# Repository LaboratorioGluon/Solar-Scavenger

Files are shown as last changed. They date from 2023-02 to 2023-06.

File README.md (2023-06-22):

# Solar Scavenger

Os presento el barco **Solar Scavenger** participante de la VI Regata Solar en Baiona!

El resultado: Primer premio en diseño y tercero en regata!

Todo está desarrollado en directo, desde la PCB, diseño 3D, software y montaje! (Link abajo)

## Materiales usados:

| Nombre | Descripción |
|---|---|
| [A2212 1000 KV](https://s.click.aliexpress.com/e/_DB0ZUoN) | Motor brushless outrunner para el barco|
| [ESC 4S 40A](https://s.click.aliexpress.com/e/_DB3iqU5) | Controlador de velocidad ESC |
| [ESP32](https://s.click.aliexpress.com/e/_DdJJJ5L) | Cerebro del controlador |

## PCB

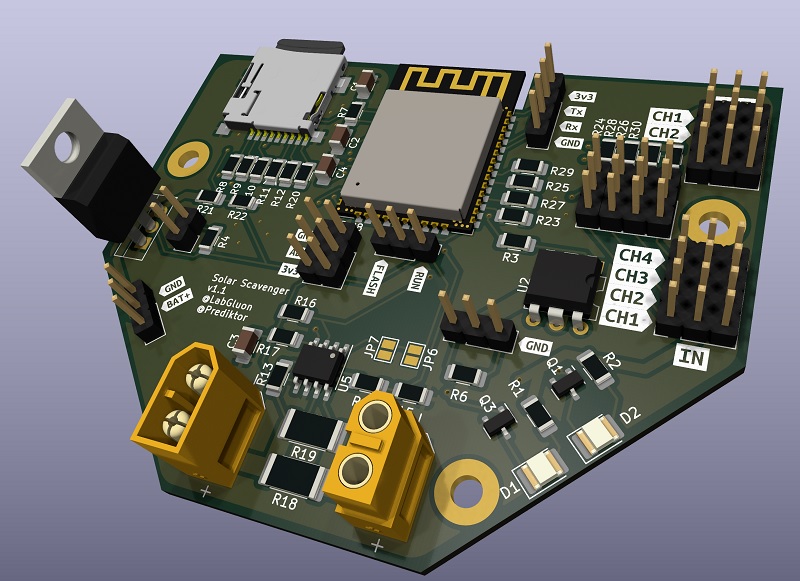
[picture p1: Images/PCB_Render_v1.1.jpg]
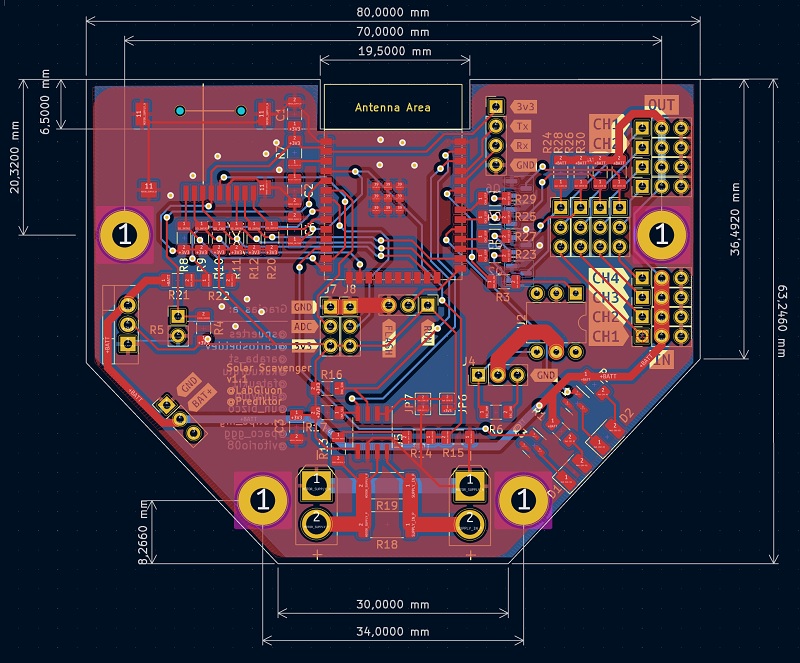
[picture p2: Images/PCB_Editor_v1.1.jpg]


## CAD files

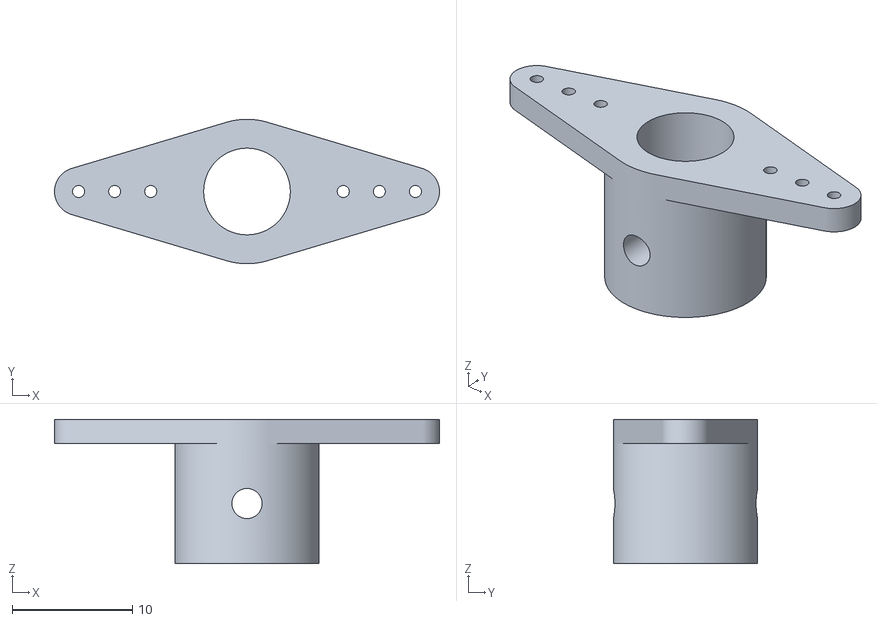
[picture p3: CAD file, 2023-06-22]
3D/stls/Caja_Control/SoporteEje - Part 1.stl
32.0 x 12.0 x 12.0

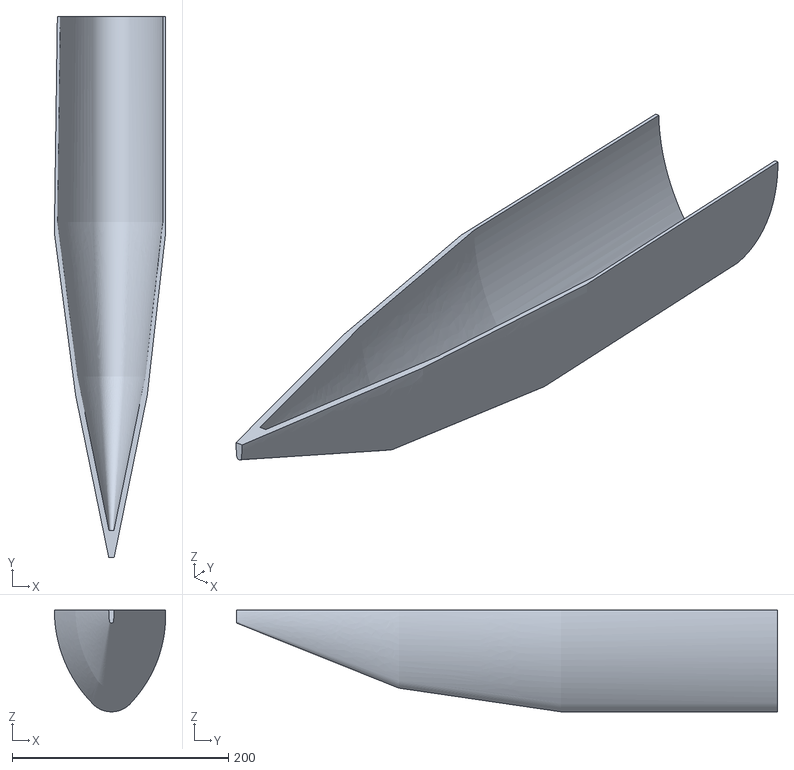
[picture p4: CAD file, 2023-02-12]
3D/stls/Casco_barco-Cut.stl
102.9 x 500.0 x 94.0

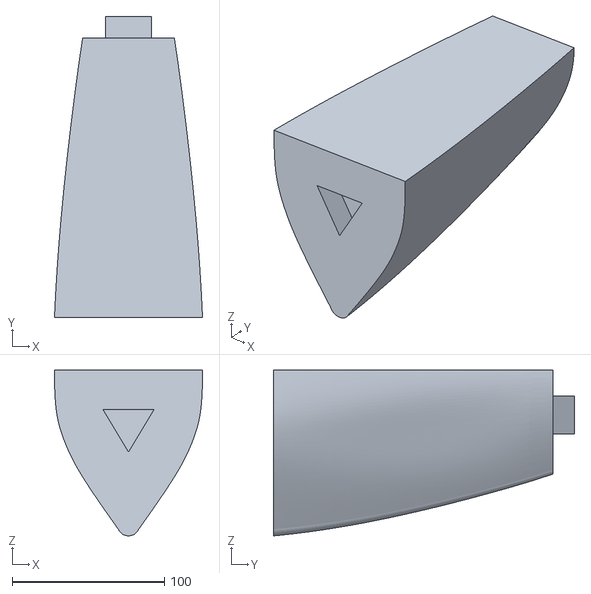
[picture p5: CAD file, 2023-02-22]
3D/stls/Casco_barco/Casco2.stl
97.4 x 198.0 x 109.1

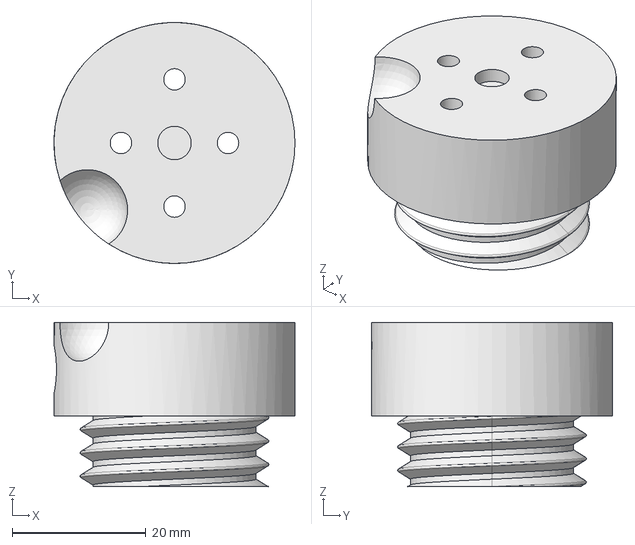
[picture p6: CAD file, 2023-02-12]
3D/Direccion_sg90.FCStd
36.0 x 36.0 x 24.5 mm

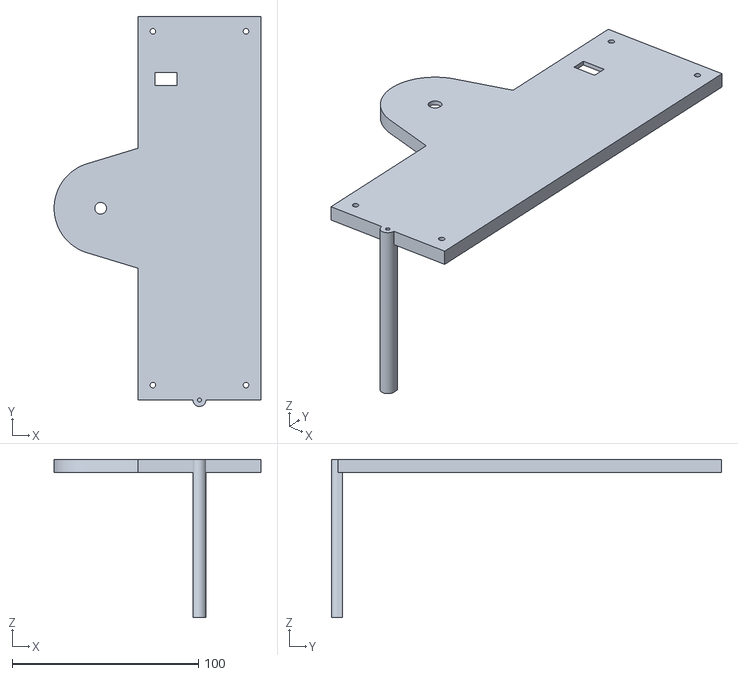
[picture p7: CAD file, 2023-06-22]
3D/stls/Caja_Control/CajaControl_Tapa.stl
111.1 x 209.5 x 85.0

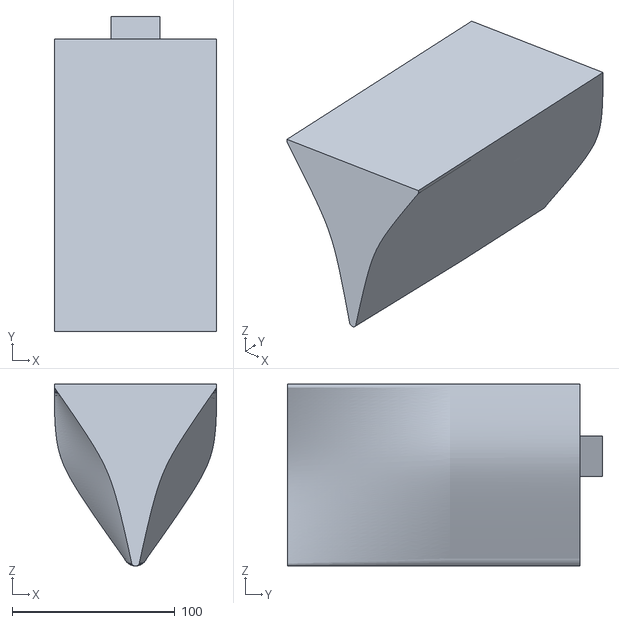
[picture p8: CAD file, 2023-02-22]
3D/stls/Casco_barco/Casco6_cola.stl
100.0 x 194.0 x 112.0

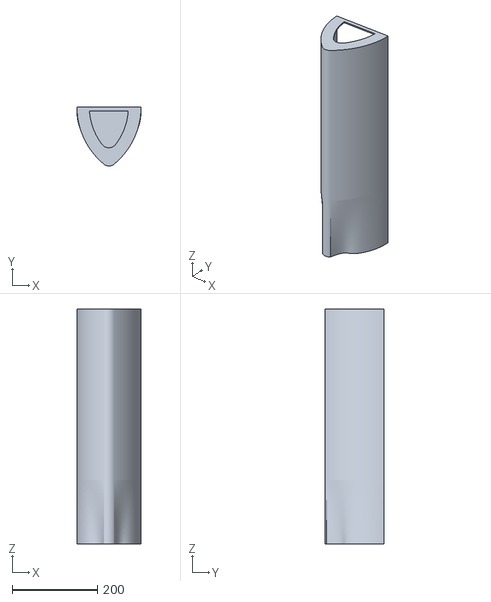
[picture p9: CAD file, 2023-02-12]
3D/stls/Hull_trasera.stl
150.5 x 138.3 x 550.0

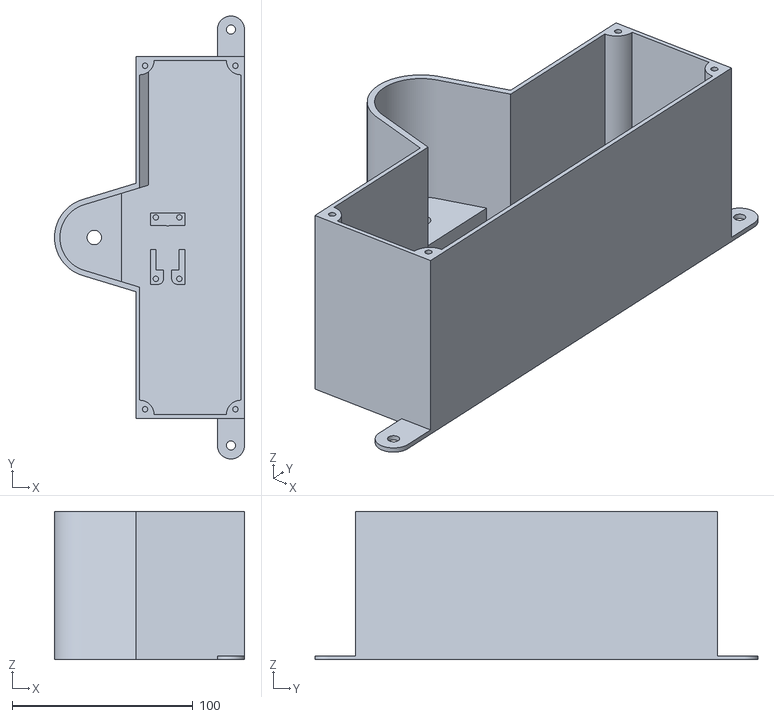
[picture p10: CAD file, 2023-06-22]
3D/stls/Caja_Control/CajaControl_principal.stl
105.1 x 245.0 x 82.0

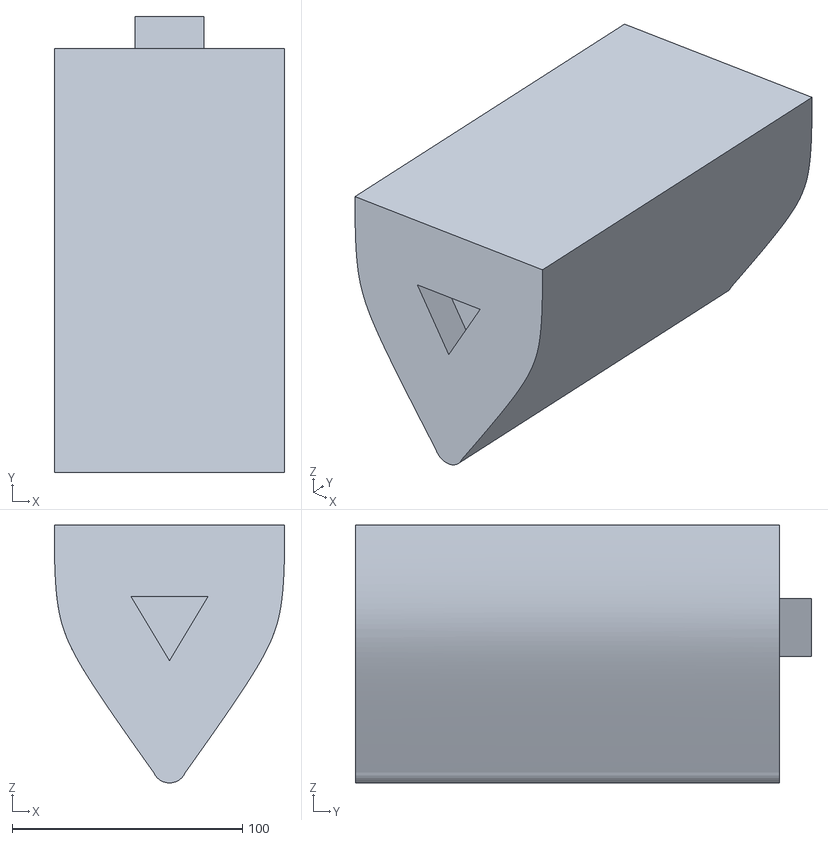
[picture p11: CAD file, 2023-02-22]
3D/stls/Casco_barco/Casco4.stl
100.0 x 198.0 x 112.0

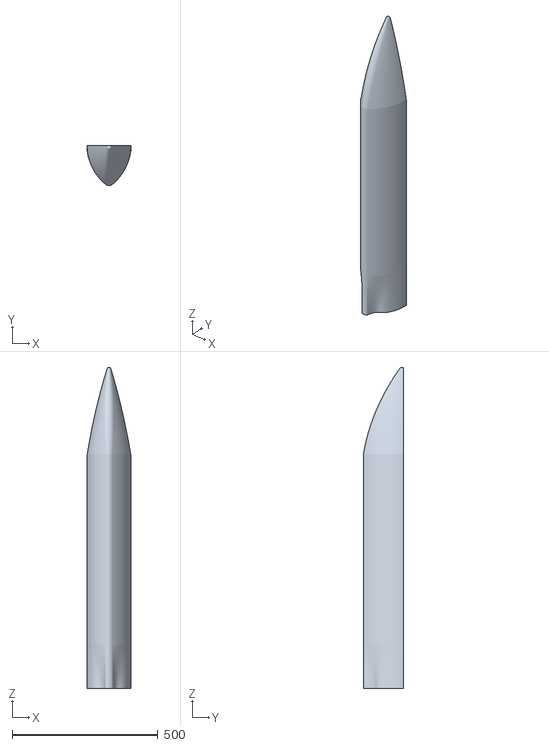
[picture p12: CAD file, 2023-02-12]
3D/stls/Hull_v01.stl
150.5 x 138.2 x 1100.0

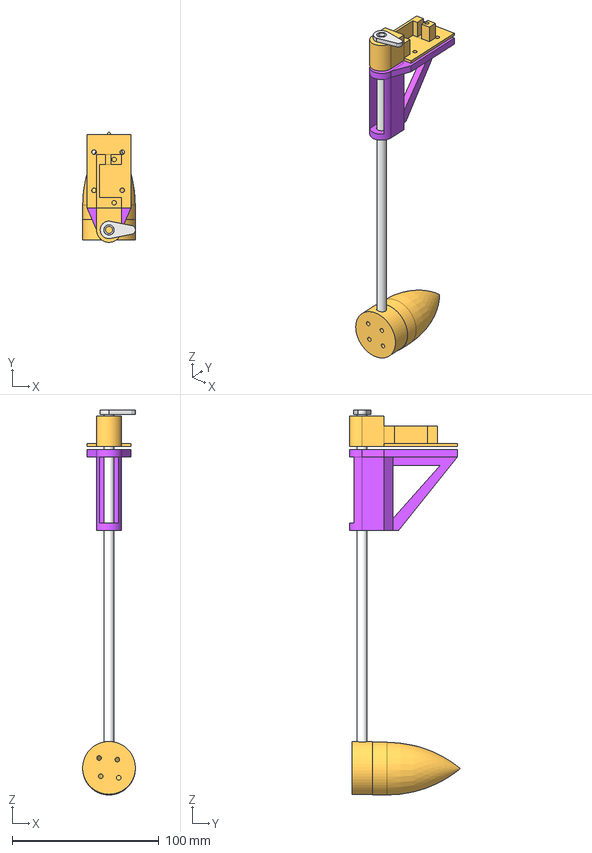
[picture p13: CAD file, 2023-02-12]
3D/Direccion_sg90_v2.FCStd
36.0 x 75.5 x 262.5 mm
SoporteSevo
EjeDireccion
EjeSaliente
AletaSoporte

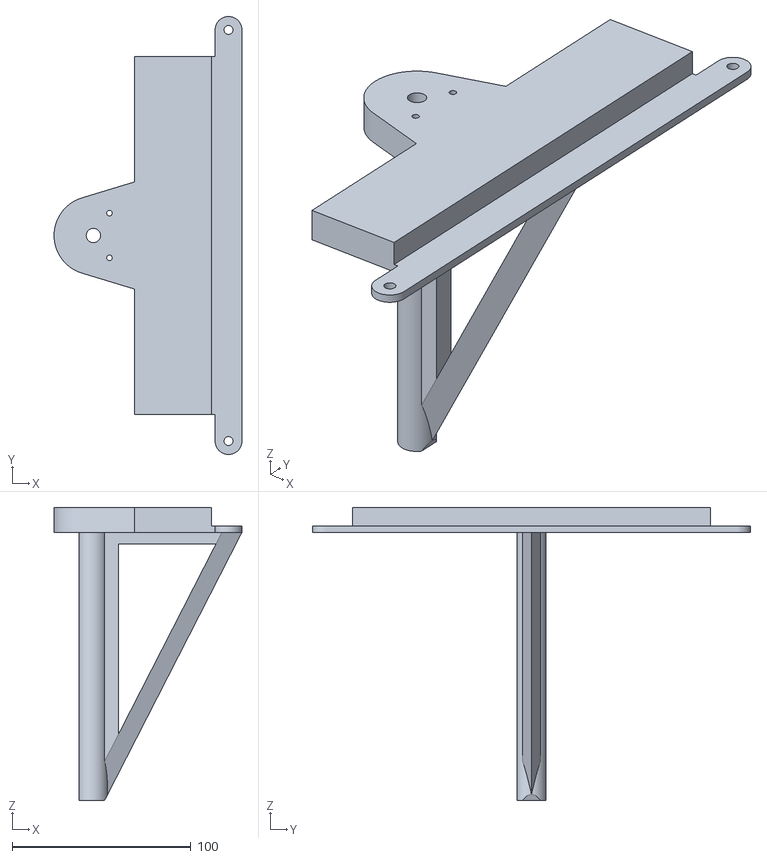
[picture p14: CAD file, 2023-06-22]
3D/stls/Caja_Control/CajaControl_Eje.stl
105.1 x 245.0 x 164.0

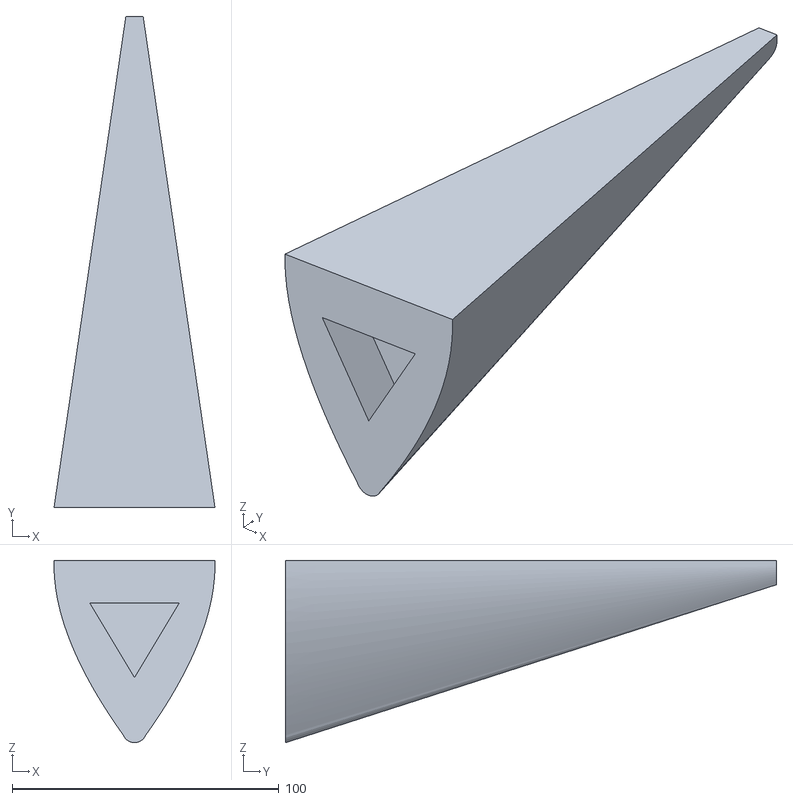
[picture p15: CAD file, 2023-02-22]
3D/stls/Casco_barco/Casco1_punta.stl
60.3 x 184.0 x 68.4

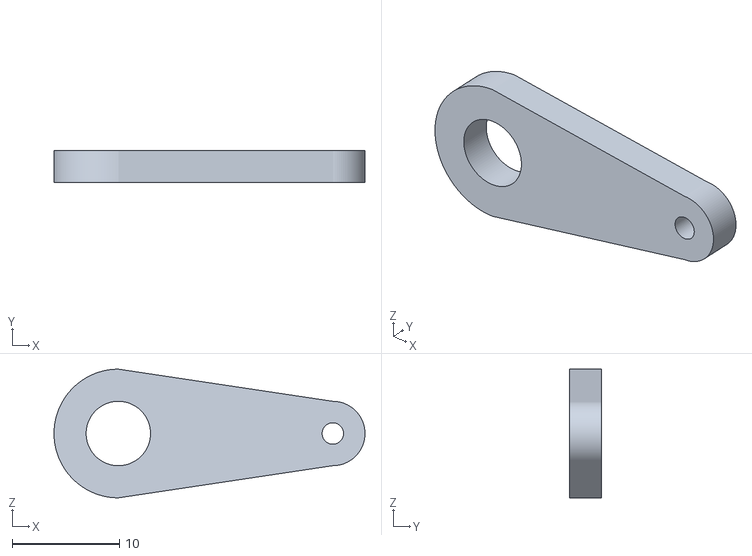
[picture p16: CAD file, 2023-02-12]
3D/stls/Test_Soporte_Brazo.stl
29.0 x 3.00 x 12.0

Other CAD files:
3D/Casco_barco.FCStd
3D/Casco_barco_v0.FCStd
3D/stls/Casco_barco/Casco5.stl
3D/stls/Direccion_sg90-AletaSoporte.stl
3D/Casco v14.f3d
3D/Direccion_sg90_v1.FCStd
3D/stls/Casco_barco/Casco3.stl
3D/stls/Direccion_sg90-AletaSoporte_v2.stl
3D/stls/Direccion_sg90-Body.stl
3D/stls/Direccion_sg90-Body_v2.stl
3D/stls/Hull_frontal.stl
3D/stls/Test_Soporte_Barra.stl
3D/stls/Test_Soporte_Servo.stl

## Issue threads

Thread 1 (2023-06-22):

Mejoras V2.0

LaboratorioGluon, 2023-06-22:
Elemento identificación (Algo llamativo)
Menos peso (y corchopan?)
Pitorrillo de motor
Hélice más pequeña y que gire más rápido
Dirección por timón
--> Trimarán?? (Ha ganado en la encuenta de expertos)
Más estrechos, porqué? (En piragüas se nota, más afilado -> más rapido)
Hidrojet (Si lo encontramos)

== Electronica/Sw ==
LEds de colores ?
Interruptor on/off
Condensadores
// Poner RTC en la electrónica? Poder diferenciar carreras/tiempos/eventos
Añadir GPS/IMU
Añadir todos los datos a la SD
EEPROM para guardar datos?

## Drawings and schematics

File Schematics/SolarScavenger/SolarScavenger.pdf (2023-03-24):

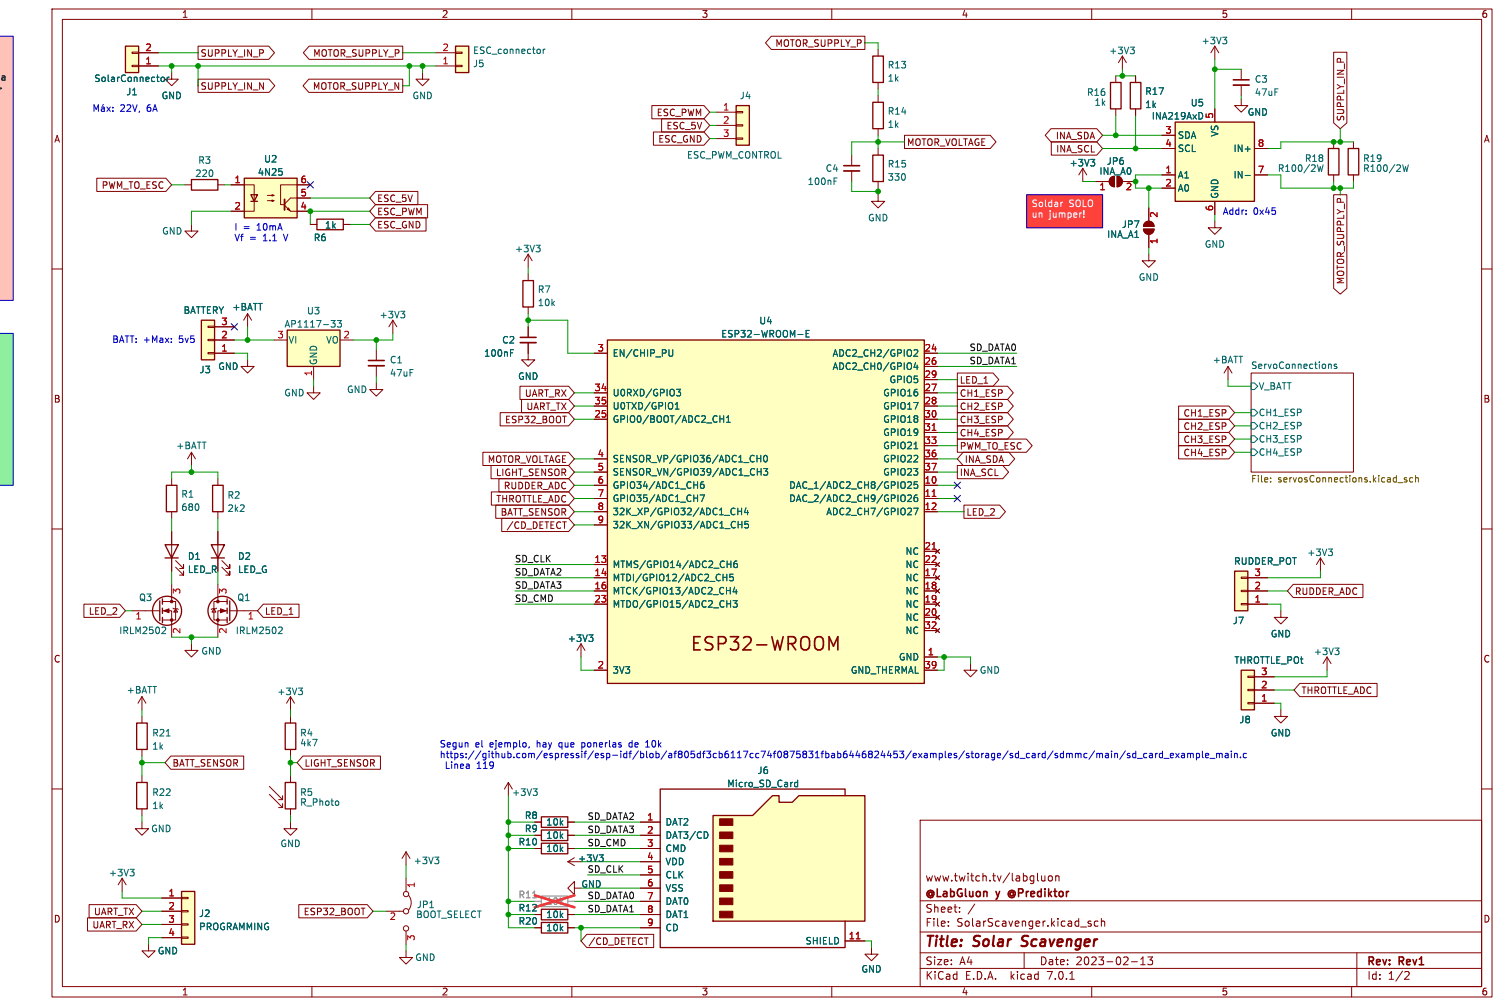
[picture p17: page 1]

þÿMáx: 22V, 6A Release Notes v1.1 TODOS:
[X] Fix: Enable chip + þÿAñadir RC al pin 3

Segun el ejemplo, hay que ponerlas de 10k https://github.com/espressif/esp-idf/blob/af805df3cb6117cc74f0875831fbab6446824453/examples/storage/sd_card/sdmmc/main/sd_card_example_main.c Linea 119 BATT: +Max: 5v5

www.twitch.tv/labgluon
Id: 1/2 Title: Solar Scavenger File: SolarScavenger.kicad_sch Sheet: / @LabGluon y @Prediktor

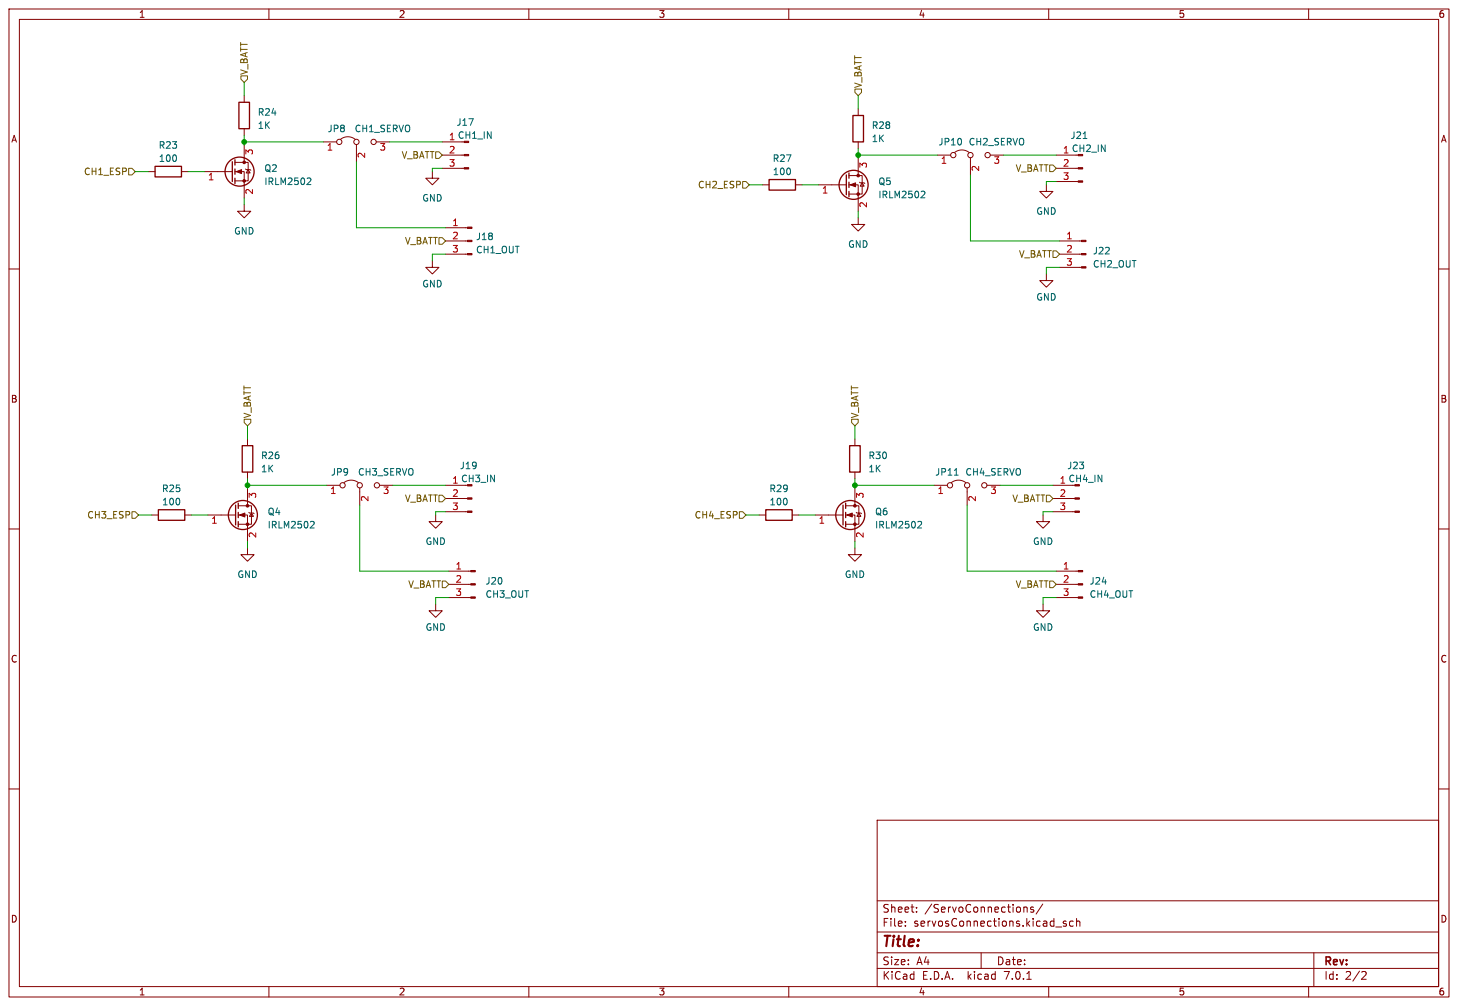
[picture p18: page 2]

Id: 2/2 Title: File: servosConnections.kicad_sch Sheet: /ServoConnections/

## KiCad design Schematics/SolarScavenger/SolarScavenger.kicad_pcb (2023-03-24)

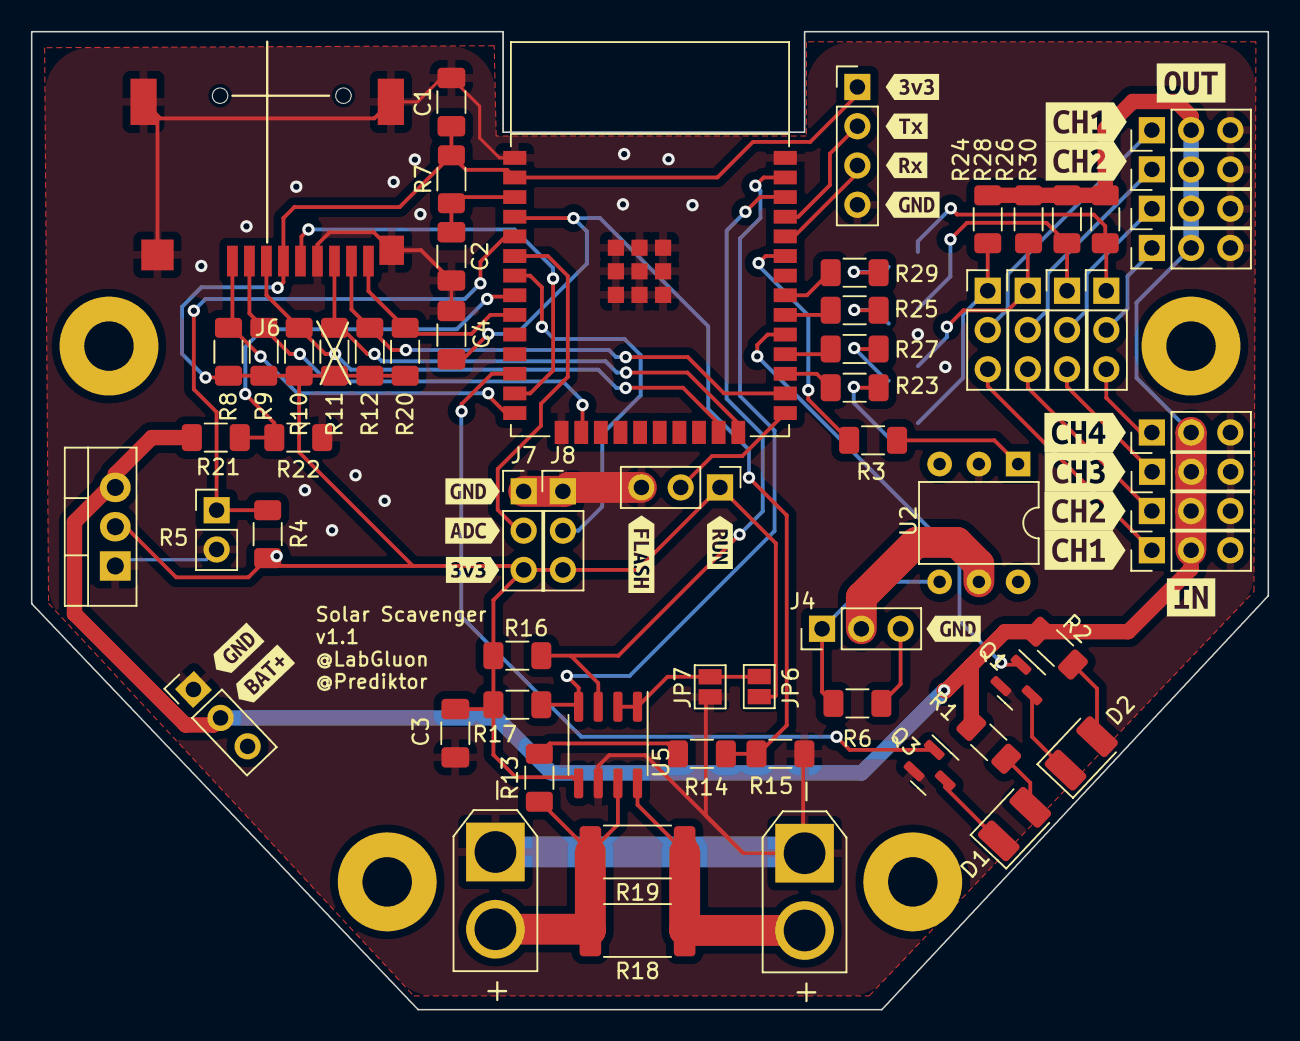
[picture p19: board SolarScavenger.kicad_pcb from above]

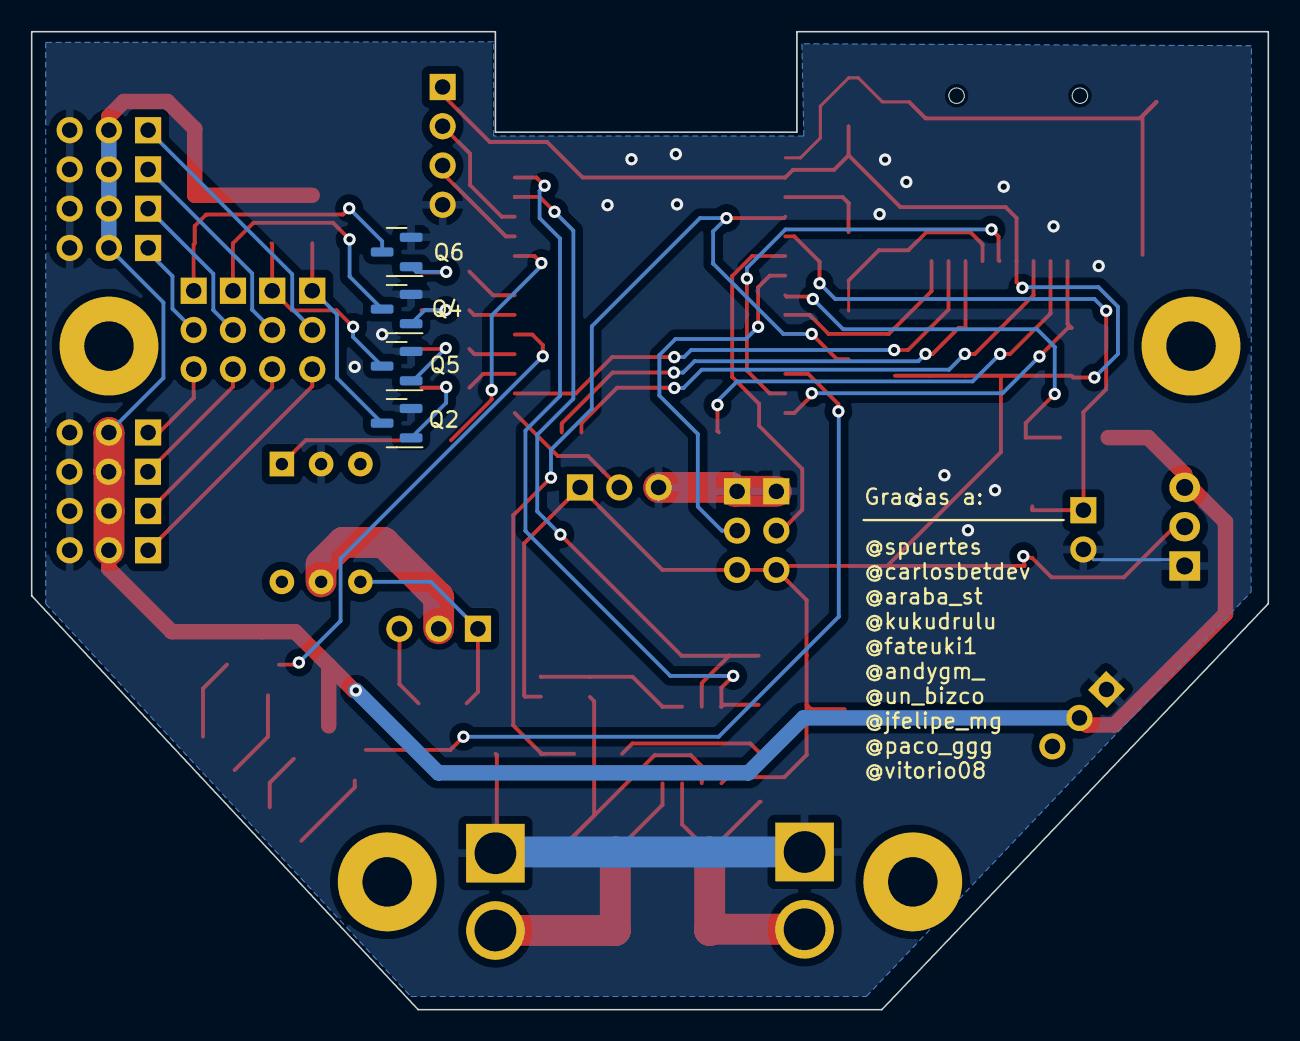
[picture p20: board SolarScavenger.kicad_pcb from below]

Board: 2 copper layers, 80.0 x 63.3 mm, 89 parts (4 on the bottom side), 56 nets.

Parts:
C1, C3: 47uF; C_1206_3216Metric_Pad1.33x1.80mm_HandSolder
C2, C4: 100nF; C_1206_3216Metric_Pad1.33x1.80mm_HandSolder
D1: LED_R; LED_1210_3225Metric_Pad1.42x2.65mm_HandSolder
D2: LED_G; LED_1210_3225Metric_Pad1.42x2.65mm_HandSolder
J1: SolarConnector; AMASS_XT30U-M_1x02_P5.0mm_Vertical
J2: PROGRAMMING; PinHeader_1x04_P2.54mm_Vertical
J3: BATTERY; PinHeader_1x03_P2.54mm_Vertical
J4: ESC_PWM_CONTROL; PinHeader_1x03_P2.54mm_Vertical
J5: ESC_connector; AMASS_XT30U-M_1x02_P5.0mm_Vertical
J6: Micro_SD_Card; microSD-Receptacle-SelfEject
J7: RUDDER_POT; PinHeader_1x03_P2.54mm_Vertical
J8: THROTTLE_POt; PinHeader_1x03_P2.54mm_Vertical
J17: CH1_IN; PinHeader_1x03_P2.54mm_Vertical
J18: CH1_OUT; PinHeader_1x03_P2.54mm_Vertical
J19: CH3_IN; PinHeader_1x03_P2.54mm_Vertical
J20: CH3_OUT; PinHeader_1x03_P2.54mm_Vertical
J21: CH2_IN; PinHeader_1x03_P2.54mm_Vertical
J22: CH2_OUT; PinHeader_1x03_P2.54mm_Vertical
J23: CH4_IN; PinHeader_1x03_P2.54mm_Vertical
J24: CH4_OUT; PinHeader_1x03_P2.54mm_Vertical
JP1: BOOT_SELECT; PinHeader_1x03_P2.54mm_Vertical
JP6: INA_A0; SolderJumper-2_P1.3mm_Open_Pad1.0x1.5mm
JP7: INA_A1; SolderJumper-2_P1.3mm_Open_Pad1.0x1.5mm
JP8: CH1_SERVO; PinHeader_1x03_P2.54mm_Vertical
JP9: CH3_SERVO; PinHeader_1x03_P2.54mm_Vertical
JP10: CH2_SERVO; PinHeader_1x03_P2.54mm_Vertical
JP11: CH4_SERVO; PinHeader_1x03_P2.54mm_Vertical
Q1, Q2, Q3, Q4, Q5, Q6: IRLM2502; SOT-23
R1: 680; R_1206_3216Metric_Pad1.30x1.75mm_HandSolder
R2: 2k2; R_1206_3216Metric_Pad1.30x1.75mm_HandSolder
R3: 220; R_1206_3216Metric_Pad1.30x1.75mm_HandSolder
R4: 4k7; R_1206_3216Metric_Pad1.30x1.75mm_HandSolder
R5: R_Photo; PinHeader_1x02_P2.54mm_Vertical
R6, R13, R14, R16, R17, R21, R22: 1k; R_1206_3216Metric_Pad1.30x1.75mm_HandSolder
R7, R8, R9, R10, R11, R12, R20: 10k; R_1206_3216Metric_Pad1.30x1.75mm_HandSolder
R15: 330; R_1206_3216Metric_Pad1.30x1.75mm_HandSolder
R18, R19: R100/2W; R_2512_6332Metric_Pad1.40x3.35mm_HandSolder
R23, R25, R27, R29: 100; R_1206_3216Metric_Pad1.30x1.75mm_HandSolder
R24, R26, R28, R30: 1K; R_1206_3216Metric_Pad1.30x1.75mm_HandSolder
U2: 4N25; DIP-6_W7.62mm
U3: AP1117-33; TO-220-3_Vertical
U4: ESP32-WROOM-E; ESP32-WROOM-32E
U5: INA219AxD; SOIC-8_3.9x4.9mm_P1.27mm
kibuzzard-63EE93D3: G***; kibuzzard-63EE93D3
kibuzzard-63EE93FE, kibuzzard-63EE93FE#2: G***; kibuzzard-63EE93FE
kibuzzard-63EE940D: G***; kibuzzard-63EE940D
kibuzzard-63EE941D: G***; kibuzzard-63EE941D
kibuzzard-63EE9448: G***; kibuzzard-63EE9448
kibuzzard-63F11AB2: G***; kibuzzard-63F11AB2
kibuzzard-63F11AB7: G***; kibuzzard-63F11AB7
kibuzzard-63F11AC7: G***; kibuzzard-63F11AC7
kibuzzard-63F11AD1: G***; kibuzzard-63F11AD1
kibuzzard-63F11F4E: G***; kibuzzard-63F11F4E
kibuzzard-63F11F5A: G***; kibuzzard-63F11F5A
kibuzzard-63F118E7: G***; kibuzzard-63F118E7
kibuzzard-63F118F7: G***; kibuzzard-63F118F7
kibuzzard-63F127EF: G***; kibuzzard-63F127EF
kibuzzard-63F1280A: G***; kibuzzard-63F1280A
kibuzzard-63F12006: G***; kibuzzard-63F12006
kibuzzard-63F12026, kibuzzard-63F12026#2: G***; kibuzzard-63F12026
kibuzzard-63F12816: G***; kibuzzard-63F12816

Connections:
+3V3: C1.1, C3.1, J2.1, J6.4 (VDD), J7.3, J8.3, JP1.1 (A), JP6.1 (A), R4.1, R7.2, R8.2, R9.2, R10.2, R11.2, R12.2, R16.2, R17.2, R20.2, U3.2 (VO), U4.2 (3V3), U5.5 (VS)
+BATT: J3.2, J17.2, J18.2, J19.2, J20.2, J21.2, J22.2, J23.2, J24.2, R1.1, R2.1, R21.1, R24.2, R26.2, R28.2, R30.2, U3.3 (VI)
/SD_CLK: J6.5 (CLK), U4.13 (MTMS/GPIO14/ADC2_CH6)
/SD_CMD: J6.3 (CMD), R10.1, U4.23 (MTDO/GPIO15/ADC2_CH3)
/SD_DATA0: J6.7 (DAT0), R11.1, U4.24 (ADC2_CH2/GPIO2)
/SD_DATA1: J6.8 (DAT1), R12.1, U4.26 (ADC2_CH0/GPIO4)
/SD_DATA2: J6.1 (DAT2), R8.1, U4.14 (MTDI/GPIO12/ADC2_CH5)
/SD_DATA3: J6.2 (DAT3/CD), R9.1, U4.16 (MTCK/GPIO13/ADC2_CH4)
BATT_SENSOR: R21.2, R22.1, U4.8 (32K_XP/GPIO32/ADC1_CH4)
CH1_ESP: R23.1, U4.27 (GPIO16)
CH2_ESP: R27.1, U4.28 (GPIO17)
CH3_ESP: R25.1, U4.30 (GPIO18)
CH4_ESP: R29.1, U4.31 (GPIO19)
ESC_5V: J4.2, U2.5
ESC_GND: J4.3, R6.2
ESC_PWM: J4.1, R6.1, U2.4
ESP32_BOOT: JP1.2 (C), U4.25 (GPIO0/BOOT/ADC2_CH1)
INA_SCL: R17.1, U4.37 (GPIO23), U5.4 (SCL)
INA_SDA: R16.1, U4.36 (GPIO22), U5.3 (SDA)
LED_1: Q1.1 (G), U4.29 (GPIO5)
LED_2: Q3.1 (G), U4.12 (ADC2_CH7/GPIO27)
LIGHT_SENSOR: R4.2, R5.1, U4.5 (SENSOR_VN/GPIO39/ADC1_CH3)
MOTOR_SUPPLY_N: C1.2, C2.2, C3.2, C4.2, J1.1, J2.4, J3.1, J5.1, J6.6 (VSS), J6.11 (SHIELD), J7.1, J8.1, J17.3, J18.3, J19.3, J20.3, J21.3, J22.3, J23.3, J24.3, JP1.3 (B), JP7.1 (A), Q1.2 (S), Q2.2 (S), Q3.2 (S), Q4.2 (S), Q5.2 (S), Q6.2 (S), R5.2, R15.1, R22.2, U2.2, U3.1 (GND), U4.1 (GND), U4.15 (GND), U4.38 (GND), U4.39 (GND_THERMAL), U5.6 (GND)
MOTOR_SUPPLY_P: J5.2, R13.2, R18.2, R19.2, U5.7 (IN-)
MOTOR_VOLTAGE: C4.1, R14.1, R15.2, U4.4 (SENSOR_VP/GPIO36/ADC1_CH0)
unnamed: D1.2 (A), R1.2
unnamed: D1.1 (K), Q3.3 (D)
unnamed: D2.2 (A), R2.2
unnamed: D2.1 (K), Q1.3 (D)
unnamed: J17.1, JP8.3 (B)
unnamed: J18.1, JP8.2 (C)
unnamed: J19.1, JP9.3 (B)
unnamed: J20.1, JP9.2 (C)
unnamed: J21.1, JP10.3 (B)
unnamed: J22.1, JP10.2 (C)
unnamed: J23.1, JP11.3 (B)
unnamed: J24.1, JP11.2 (C)
unnamed: JP6.2 (B), JP7.2 (B), U5.1 (A1), U5.2 (A0)
unnamed: JP8.1 (A), Q2.3 (D), R24.1
unnamed: JP9.1 (A), Q4.3 (D), R26.1
unnamed: JP10.1 (A), Q5.3 (D), R28.1
unnamed: JP11.1 (A), Q6.3 (D), R30.1
unnamed: Q2.1 (G), R23.2
unnamed: Q4.1 (G), R25.2
unnamed: Q5.1 (G), R27.2
unnamed: Q6.1 (G), R29.2
unnamed: R3.2, U2.1
unnamed: R13.1, R14.2
unnamed: C2.1, R7.1, U4.3 (EN/CHIP_PU)
PWM_TO_ESC: R3.1, U4.33 (GPIO21)
RUDDER_ADC: J7.2, U4.6 (GPIO34/ADC1_CH6)
SUPPLY_IN_P: J1.2, R18.1, R19.1, U5.8 (IN+)
THROTTLE_ADC: J8.2, U4.7 (GPIO35/ADC1_CH7)
UART_RX: J2.3, U4.34 (U0RXD/GPIO3)
UART_TX: J2.2, U4.35 (U0TXD/GPIO1)
/CD_DETECT: J6.9 (CD), R20.1, U4.9 (32K_XN/GPIO33/ADC1_CH5)

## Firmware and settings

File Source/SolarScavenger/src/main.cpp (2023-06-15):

#include <stdio.h>
#include "freertos/FreeRTOS.h"
#include "freertos/task.h"
#include "mppt.h"
#include "simul.h"
#include "rcpwm.h"
#include "comms.h"
#include "secret.h"
#include "adc.h"
#include "esp_log.h"
#include "sd.h"
#include "currentSensor.h"
#include "common.h"

#define SIMUL_ON

extern "C" void app_main(void);

// Move to Config.h
#define CALIBRATE_MOTOR 0
#define LED_RED_PIN    GPIO_NUM_27 
#define LED_GREEN_PIN  GPIO_NUM_5
#define LDR_PIN        GPIO_NUM_39
#define CMD_MPPT_LIMIT 998

uint8_t isFreshStart;

static const char* TAG = "Main";

//Simul simul;
extern Comms gComms;

#ifdef MANDO

    AdcReader Throttle(1, ADC_CHANNEL_7);
    AdcReader Rudder(1, ADC_CHANNEL_6);
    RcPwm servoPower(LEDC_CHANNEL_0, GPIO_NUM_18, true);
    RcPwm servoSignal(LEDC_CHANNEL_1, GPIO_NUM_17, true);
    RcPwm servoBattery(LEDC_CHANNEL_2, GPIO_NUM_16, true);

    AdcReader LDR(1, ADC_CHANNEL_3);


#else // BARCO
    Mppt mppt;
    RcPwm motor(LEDC_CHANNEL_1, GPIO_NUM_21);
    RcPwm servo(LEDC_CHANNEL_0, GPIO_NUM_16, true);

    SdWritter sdCard;

    AdcReader LDR(1, ADC_CHANNEL_3);
    AdcReader BatteryLevel(1, ADC_CHANNEL_4);
    AdcReader motorVoltage(1, ADC_CHANNEL_0);
    CurrentSensor Ina(GPIO_NUM_22, GPIO_NUM_23, 0x45);

#endif 


void waitForChar(){
    char b;
    do{
        b = getchar();
        vTaskDelay(pdMS_TO_TICKS(100));
    }while(b == 0xFF);
}



void Restart()
{
    esp_restart();
}

void Error()
{
    // Parar motor

    // Parpadear
    while(true){
        //LED rojo ON
        vTaskDelay(pdMS_TO_TICKS(500));
        //LED rojo OFF
        vTaskDelay(pdMS_TO_TICKS(500));
    }

}

void Init()
{
    gpio_config_t leds;
    leds.intr_type = GPIO_INTR_DISABLE;
    leds.mode = GPIO_MODE_OUTPUT;
    leds.pin_bit_mask = (1 << LED_GREEN_PIN) | (1 << LED_RED_PIN);
    leds.pull_down_en = GPIO_PULLDOWN_DISABLE;
    leds.pull_up_en = GPIO_PULLUP_DISABLE;
    
    gpio_config(&leds);
    gpio_set_level(LED_GREEN_PIN, 0);
    gpio_set_level(LED_RED_PIN, 0);

#if MANDO
    gComms.Init();
    gComms.activateReception();
    servoPower.Init();
    servoSignal.Init();
    servoPower.Init();
    Throttle.Init();
    servoBattery.Init();
    servoPower.setPowerPercentage(0);
    servoSignal.setPowerPercentage(0);
    servoBattery.setPowerPercentage(0);
    vTaskDelay(pdMS_TO_TICKS(1000));
    servoPower.setPowerPercentage(100);
    servoSignal.setPowerPercentage(100);
    servoBattery.setPowerPercentage(100);
    vTaskDelay(pdMS_TO_TICKS(1000));

    LDR.Init();
    // isMpptButton
    /*gpio_config_t mpttButtonGpio;
    mpttButtonGpio.intr_type = GPIO_INTR_DISABLE;
    mpttButtonGpio.mode = GPIO_MODE_INPUT;
    mpttButtonGpio.pin_bit_mask = (1 << LDR_PIN);
    mpttButtonGpio.pull_down_en = GPIO_PULLDOWN_DISABLE;
    mpttButtonGpio.pull_up_en = GPIO_PULLUP_DISABLE;
    
    gpio_config(&mpttButtonGpio);*/
    

#else
    gComms.Init();
    gComms.activateReception();
    sdCard.Init();
    #if CALIBRATE_MOTOR
        vTaskDelay(pdMS_TO_TICKS(2000));
        motor.Init(2000);
        printf("Connect the ESC now!\n");
        printf("Wait for 2 beeps from the ESC and press a key\n");
        waitForChar();
        motor.setPowerPercentage(0);
        printf("Wait for 1,2,3 beeps \n");
        waitForChar();
    #else
        motor.Init();
    #endif 
    servo.Init(1000, 500, 2500);
    LDR.Init();
    BatteryLevel.Init();
    motorVoltage.Init();
    Ina.Init();
#endif
}

void Wait()
{
    // Busy waiting for the ESP-NOW command to start
}

void Sail()
{


}



void app_main(void)
{
    uint8_t mac[6]= {MAC_DST};
    Init();

    
    //isFreshStart = (esp_reset_reason() == ESP_RST_POWERON);
    esp_reset_reason_t resetReason;
    resetReason = esp_reset_reason();
    if(resetReason == ESP_RST_POWERON)
    {
        gpio_set_level(LED_GREEN_PIN, 1);
    }
    else if(resetReason == ESP_RST_BROWNOUT)
    {
        gpio_set_level(LED_GREEN_PIN, 1);
        gpio_set_level(LED_RED_PIN, 1);
    }

#ifdef MANDO

    printf("Starting as MANDO\n");

    gComms.addReceiver(mac);
    commDataTx sendData;

    while(true)
    {
        sendData.rudder = (uint32_t) Rudder.ReadValue()/3.3f;
        sendData.throttle = (uint32_t) Throttle.ReadValue()/3.3f;
        sendData.isModeMppt = (uint32_t) (LDR.ReadValue() > 1500);
        gComms.sendCommData(sendData);
        ESP_LOGE(TAG, "Sending values: %lu, %lu, %lu", sendData.rudder, sendData.throttle, sendData.isModeMppt);
        ESP_LOGE(TAG, "Receiving values: Power: %lu, Batt: %lu, Signal: -%d Db", gRecvCommData.Power, gRecvCommData.BattLevel, gRecvCommData.SignalDb );
        servoPower.setPowerPercentage((uint32_t)gRecvCommData.Power/10.0f);
        servoBattery.setPowerPercentage(((uint32_t)gRecvCommData.BattLevel-3500.0f)/14.0f);
        servoSignal.setPowerPercentage(((uint32_t)gRecvCommData.SignalDb*100.0f/120.0f));


        vTaskDelay(100 / portTICK_PERIOD_MS);
    }
#else

    printf("Starting as BARCO\n");
    gComms.addReceiver(mac);

    struct   commDataTx sendData;
    uint32_t power = 0;
    int32_t  delta = 2;
    float    current = 0;
    float    emaCurrent = 0;
    float    meanCurrent = 0;
    float    voltage = 0;
    float    emaVoltage = 0;
    float    meanVoltage = 0;
    uint32_t nMeasures = 0;
    uint32_t mpptOuput = 0;

    float alpha = 0.25;
    uint8_t isMppt = 0;
    uint32_t cycle = 0;

    uint32_t last_motor_duty = 0;

    while(true)
    {

        // datosRecibidos = gRecvCommData;

        meanCurrent += Ina.readCurrentMa()/1000.0f;
        meanVoltage += (motorVoltage.ReadValue()/0.12f)/1000.0f;
        nMeasures++;

        if (gComms.checkComms())
        {

            if (cycle % 20 == 0)
            {
                current = meanCurrent / nMeasures;
                voltage = meanVoltage / nMeasures;

                // EMA Filter
                emaCurrent = current * alpha + emaCurrent * (1 - alpha);
                emaVoltage = voltage * alpha + emaVoltage * (1 - alpha);

                if (gRecvCommData.isModeMppt == 1)
                {
                    if (isMppt == 0)
                    {
                        mppt.resetMppt(last_motor_duty);
                    }
                    isMppt = 1;
                    mpptOuput = mppt.mpptIC(emaVoltage, emaCurrent);

                    ESP_LOGE(TAG, "[MPTT]%.2f;%.2f;%.2f;%.2f;%lu", current, voltage, emaCurrent, emaVoltage, mpptOuput);
                    sdCard.printf("[MPTT]%.2f;%.2f;%.2f;%.2f;%lu", current, voltage, emaCurrent, emaVoltage, mpptOuput);

                    motor.setPowerPercentage(mpptOuput);
                    last_motor_duty = mpptOuput;
                }
                else
                {
                    isMppt = 0;
                    ESP_LOGE(TAG, "[MANUAL]%lu", gRecvCommData.throttle);
                    motor.setPowerPercentage(gRecvCommData.throttle / 10);
                    last_motor_duty = gRecvCommData.throttle / 10;
                }

                nMeasures = 0;
                meanCurrent = 0;
                meanVoltage = 0;
            }

            if (cycle % 20 == 0)
            {

                ESP_LOGE(TAG, "Receiving values: Rudder: %lu, Throt: %lu", gRecvCommData.rudder, gRecvCommData.throttle);
                servo.setTargetPercentage(gRecvCommData.rudder / 10);
                if(!isMppt){
                    servo.setPowerPercentage(gRecvCommData.rudder / 10);
                    last_motor_duty = gRecvCommData.throttle / 10;
                }
                sendData.Power = (uint32_t)(emaVoltage * emaCurrent) * 10.0f;
                sendData.BattLevel = (uint32_t)BatteryLevel.ReadValue() * 2.0f;
                sendData.SignalDb = lastRssiDb;
                ESP_LOGE(TAG, "Sending values: %lu, %lu, %d", sendData.Power, sendData.BattLevel, sendData.SignalDb);
                gComms.sendCommData(sendData);
                ESP_LOGI(TAG, "[APP] Free memory: %lu bytes", esp_get_free_heap_size());
            }
        }
        else
        {
            motor.setPowerPercentage(0);
            isMppt = 0;
            last_motor_duty = 0;
        }

        // Update for target
        servo.update(10);

        vTaskDelay(pdMS_TO_TICKS(10));
        cycle++;
    }

#endif

}

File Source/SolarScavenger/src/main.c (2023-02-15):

#include <stdio.h>
//#include <inttypes.h>
//#include "sdkconfig.h"
#include "freertos/FreeRTOS.h"
#include "freertos/task.h"
//#include "freertos/queue.h"
//#include "esp_attr.h"
//#include "soc/rtc.h"
//#include "esp_system.h"
//#include "esp_flash.h"
#include "mppt.h"
#include "pwm.h"
#include "simul.h"

#define GPIO_PWM0A_OUT 21   //Set GPIO 21 as PWM0A

void app_main(void)
{
  printf("Start\n");

  mcpwm_gpio_initialize(GPIO_PWM0A_OUT);

  uint32_t read_motor_cycle = 80;
  float v = 5, i = 0;

  //Version cleanarda
  /*if( read_motor_cycle < 10 ) stop_motor();
  if( read_motor_cycle < 60 ) set_motor_duty_cycle(read_motor_cycle);
  else set_motor_duty_cycle( mppt_PO(v, i) );*/

  while(true){

      i = simul_I_panel(v);
      read_motor_cycle = mppt_PO(v, i);

      printf("Motor cycle: %d \n", read_motor_cycle);
      printf("   Power: %f \n", v * i);

      set_motor_duty_cycle( read_motor_cycle );
      v = recalculate_V(v, read_motor_cycle);
      printf("   New V: %f New I: %f \n", v, i);

      vTaskDelay(1000 / portTICK_PERIOD_MS);

  }

}

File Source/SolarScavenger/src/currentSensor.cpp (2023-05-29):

#include "currentSensor.h"
#include "esp_log.h"

static const char *TAG = "CURRENT_SENSOR";

CurrentSensor::CurrentSensor(gpio_num_t SDA, gpio_num_t SCL, uint8_t addr):
    pinSDA(SDA), pinSCL(SCL), i2cAddr(addr)
{
    
    conf.mode = I2C_MODE_MASTER;
    conf.sda_io_num = pinSDA;         // select SDA GPIO specific to your project
    conf.sda_pullup_en = GPIO_PULLUP_ENABLE;
    conf.scl_io_num = pinSCL;         // select SCL GPIO specific to your project
    conf.scl_pullup_en = GPIO_PULLUP_ENABLE;
    conf.master.clk_speed = 400000;  // select frequency specific to your project
    conf.clk_flags = 0;                          
    
}

esp_err_t CurrentSensor::Init()
{

    i2c_param_config(i2c_master_port, &conf);
    i2c_driver_install(i2c_master_port, conf.mode, 0, 0, 0);

    uint8_t reg = 0;
    uint8_t read[2]={0};
    uint8_t writeBack[4] = {0};
    esp_err_t ret;
    ret = i2c_master_write_read_device( i2c_master_port, 0x45, &reg, 1, read, 2, pdMS_TO_TICKS(1000));

    read[0] |= 0b1110 << 3;
    writeBack[0] = 0;
    writeBack[1] = read[1];
    writeBack[2] = read[0];
    i2c_master_write_read_device( i2c_master_port, 0x45, writeBack, 3, read, 2, pdMS_TO_TICKS(1000));
    ESP_LOGE(TAG, "Read (%d) : 0x%x 0x%x",ret, read[0], read[1]);

    // @TODO: Hacer un check de que hemos leido bien
    return ret;
}

uint32_t CurrentSensor::readCurrentMa()
{
    uint8_t reg = 1;
    uint8_t read[2]={0};
    i2c_master_write_read_device( i2c_master_port, 0x45, &reg, 1, read, 2, pdMS_TO_TICKS(1000));
    uint32_t valueMa = (read[0]<<8 | read[1])/5;
    //ESP_LOGE(TAG, "Read : 0x%x 0x%x -> %lu", read[0], read[1], valueMa);
    if(valueMa > 10000){
        valueMa = 0;
    }
    return valueMa;
}

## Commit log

2023-02-12 3d files v1
    [Casco_barco-Cut.stl, Casco_barco.FCStd, Casco_barco_v0.FCStd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]
2023-02-12 Added stls for ship and propellers
    [Casco v14.f3d, Casco1_punta.stl, Casco2.stl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]
2023-02-13 Boat top part heigth reduced to 2mm
    [Casco1_punta.stl, Casco2.stl, Casco3.stl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]
2023-02-15 Bajado el margen de las juntas del casco a 0.5mm
    [Casco1_punta.stl, Casco2.stl, Casco3.stl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]
2023-02-15 Primera version de 2 modos de MPPT, simulacion panel solar y pwm alfa
2023-02-18 Schematic update
    [SolarScavenger.kicad_sch]
2023-02-18 PCB final candidate
    [SolarScavenger.kicad_pcb, SolarScavenger.kicad_sch]
2023-02-18 Actual final canditate
    [SolarScavenger.kicad_pcb]
2023-02-19 Update de los interfaces SW
2023-02-19 Working motor PWM
2023-02-20 Mppt and simul reworked to c++ style
    [main.cpp]
2023-02-22 Increased margin to 1mm
    [Casco1_punta.stl, Casco2.stl, Casco3.stl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]
2023-02-23 Version 1.0 de la PCB, enviada a fabricar
    [SolarScavenger.kicad_pcb]
2023-03-05 Comms working with throttle and rudder
2023-03-07 Added SD writter and updated for IDF 5.0
    [SolarScavenger.kicad_sch]
2023-03-20 Added SD and current sensor code
2023-03-23 PCB v1.1
    [SolarScavenger.kicad_pcb, SolarScavenger.kicad_sch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]
2023-03-24 Added images and Readme
    [SolarScavenger.kicad_pcb]
2023-04-07 Working SD and PWM inverted for new PCB
    [main.cpp, sd.cpp]
2023-04-22 Added Check for comms and changed us for servo
2023-04-26 Minor fixes and added EMISOR mac to receive messages
    [main.cpp]
2023-05-28 Power is handled by MANDO too
2023-06-02 Fix MPPT not engaging
    [main.cpp]
2023-06-11 Fix ESC PWM signal
    [adc.cpp, main.cpp, rcpwm.cpp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]
2023-06-22 Updated STL files
    [CajaControl_Eje.stl, CajaControl_Tapa.stl, CajaControl_principal.stl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]
